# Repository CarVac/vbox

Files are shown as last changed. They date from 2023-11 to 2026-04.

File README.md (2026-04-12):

# vbox

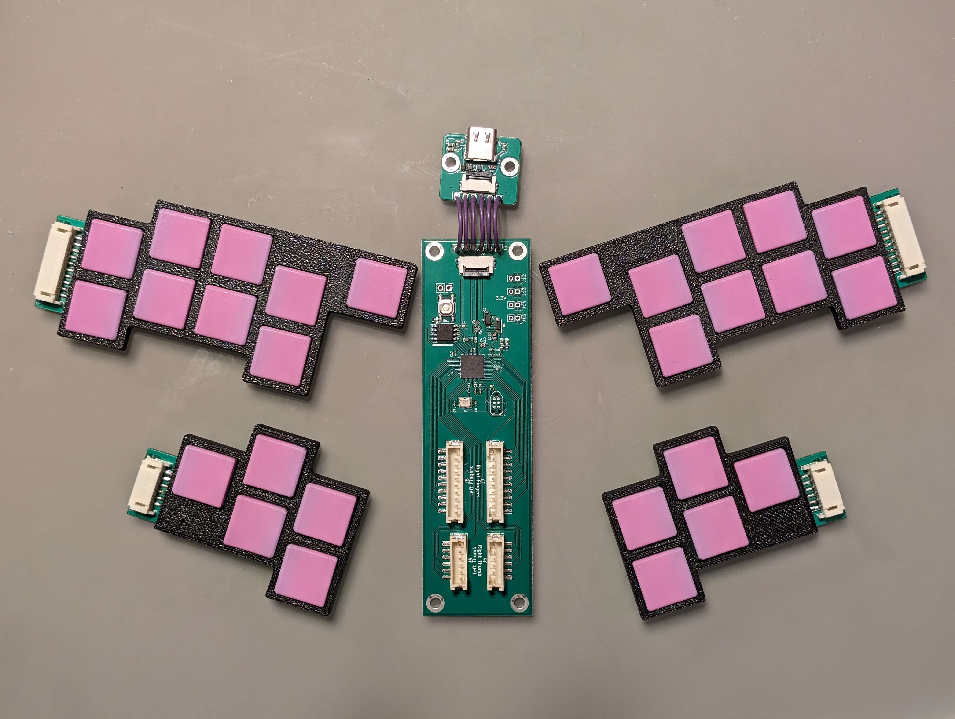
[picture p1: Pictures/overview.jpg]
Overview of pcb and hand clusters


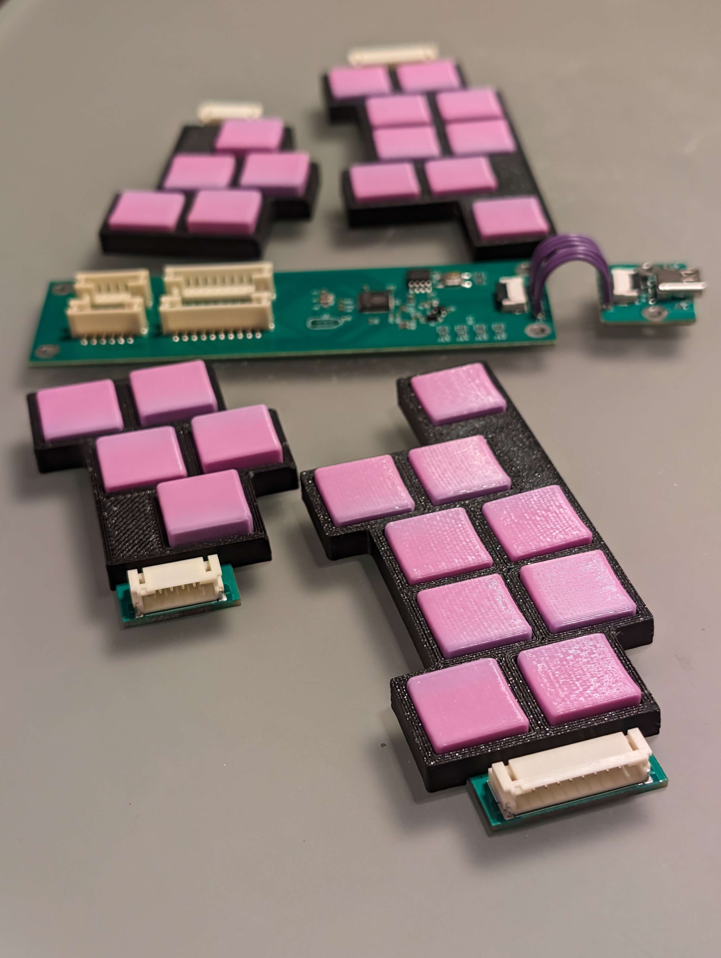
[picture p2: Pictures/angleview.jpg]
Angled view of hand clusters


A rectangle controller for Melee with buttons arranged vertically instead of on a flat surface.

It's intended to be highly modular and configurable to fit different people's button layout preferences and hand sizes.

The left- and right-hand finger clusters and thumb clusters are mirror images of each other, with shared daughterboard PCBs, each side having single-sided layouts.

The switches used are Omron D2LS-21(20M), which are easy to hand-solder. The SMD JST PH connector was chosen for its low profile and ease of hand soldering.

Any switch location can be omitted if desired, and the housing printed with a blank where it would go.

The motherboard is designed to be as narrow as possible, with 4 JST connectors for button cluster daughterboards and one FFC connector for the USB-C breakout board.

It is derived from the [Rana Labs Tadpole](https://github.com/rana-sylvatica/rana-tadpole) motherboard but with extremely heavy layout changes.

# License

This project is licensed under the CERN Open Hardware License Version 2 - Strongly Reciprocal

This license:

* Allows use, reproduction, modification, distribution, and sale of the design
* Requires distribution under the same terms and attribution to the original designer(s)
* Does not grant trademark rights
* May be terminated for non-compliance

If you are distributing vboxes or derivatives, you must provide a way for the recipient to access the source files (this repository or your fork if you modify it).

All of these files are posted as-is. This source is distributed WITHOUT ANY EXPRESS OR IMPLIED WARRANTY, INCLUDING OF MERCHANTABILITY, SATISFACTORY QUALITY, AND FITNESS FOR A PARTICULAR PURPOSE.

# BOM

## PCBs

* Motherboard (with SMT assembly)
* [QuRB](https://github.com/rana-sylvatica/QuRB)) (with SMT assembly) (USB-C breakout)
* 2x finger daughterboards (for hand assembly)
* 2x thumb daughterboards (for hand assembly)

## Electrical Parts

* 20x (or more) Omron D2LS-21(20M) mouse switches
* 2x S6B-PH-SM4-TB 6-pin right-angle surface-mount JST PH
* 2x S10B-PH-SM4-TB 10-pin right-angle surface-mount JST PH
* 2x A06KR06KR26E152A 6-pin 6" JST KR (PH-compatible) cable assembly, reversed
* 2x A10KR10KR26E102A 10-pin 4" JST KR (PH-compatible) cable assembly, reversed
* 1x 12-pin 0.5mm pitch ribbon cable, Xmm long

## Printed Parts

The housings may be customized to include or omit different button locations. Adjust the python file (which uses Build123D) where it says `EDIT THESE TO REMOVE BUTTON HOLES` and run the file to generate new STLs.

Print as many keycaps as necessary.

* Left Finger Cluster Housing
* Right Finger Cluster Housing
* Left Thumb Cluster Housing
* Right Thumb Cluster Housing
* 17x (or more) Short Keycaps
* 3x (or more) Tall Keycaps

Housing TBD; there may be a non-folding version and a folding version.

# Using the Motherboard with Other Button Clusters

You can use the motherboard with other finger clusters as long as you design them properly. The motherboard JST pinout is listed following, according to standard OpenFrame1 button locations.

## Pinout

### Left Hand Fingers

1. GND
2. Upper Row Index Finger (optional, GPIO 11)
3. Upper Row Ring Finger (optional, GPIO 23)
4. Upper Row Pinky Finger (optional, GPIO 25)
5. L
6. Analog Stick Left
7. Analog Stick Down
8. Analog Stick Right
9. Upper Row Middle Finger (optional, GPIO 1)
10. Start

### Right Hand Fingers

1. GND
2. Right Hand Start (optional, GPIO 29)
3. R
4. B
5. Y
6. X
7. Lightshield
8. Z
9. Midshield
10. Analog Stick Up

### Left Hand Thumbs

1. GND
2. Modifier 5 (optional, GPIO 10) (mirrored location of C-Stick Right)
3. Modifier 4 (optional, GPIO 9) (mirrored location of C-Stick Up)
4. Modifier 3 (optional, GPIO 8) (mirrored location of C-Stick Left)
5. ModY (mirrored location of C-Stick Down)
6. ModX (mirrored location of A)

### Right Hand Thumbs

1. GND
2. C-Stick Right
3. C-Stick Down
4. A
5. C-Stick Left
6. C-Stick Up

## Modifications

You may use as many or as few buttons as you would like, but keep in mind that if you are intending this for melee you should at least populate the standard 20 OpenFrame1 buttons.

When the JSTs of the button clusters are mounted on the **top side of the outer edges** of the PCBs (as in the reference design) or the **bottom side of the inner edges** of the PCBs, the pinout should be the same as on the motherboard, and you must use "reversed" cable assemblies which map pin 1 to pin 1 and pin N to pin N.

When the JSTs of the button clusters are mounted on the **bottom side of the outer edges** of the PCBs or the **top side of the inner edges** of the PCBs, the pinout should be reversed relative to the motherboard (1 to 10 and 10 to 1 for the fingers, and 1 to 6 and 6 to 1 for the thumb clusters) and you must use "non-reversed" (they simply omit the word reversed) cable assemblies that connect pin 1 to pin N. The correct cable assemblies are listed below:

* 2x A06KR06KR26E152**B** 6-pin 6" JST KR (PH-compatible) cable assembly, ***non-reversed***
* 2x A10KR10KR26E102**B** 10-pin 4" JST KR (PH-compatible) cable assembly, ***non-reversed***

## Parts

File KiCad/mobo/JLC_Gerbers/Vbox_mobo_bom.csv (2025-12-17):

Comment | Designator | Footprint | LCSC
1uF | C1,C2,C4,C10 | Capacitor_SMD:C_0402_1005Metric | C52923
100nF | C3,C5,C6,C11,C12,C13,C14,C15,C16,C17 | Capacitor_SMD:C_0402_1005Metric | C1525
22pF | C7,C8 | Capacitor_SMD:C_0402_1005Metric | C1555
10uF | C9 | Capacitor_SMD:C_0402_1005Metric | C15525
Schottky Diode | D1 | Diode_SMD:D_SOD-123 | C8598
Conn_01x06 | J4,J5 | Connector_JST:JST_PH_B6B-PH-SM4-TB_1x06-1MP_P2.00mm_Vertical | C471518
Conn_01x10 | J6,J7 | Connector_JST:JST_PH_B10B-PH-SM4-TB_1x10-1MP_P2.00mm_Vertical | C264997
2k | R1,R2,R3,R4,R12,R13,R14,R15,R16,R17,R18,R19,R20,R21,R22,R23,R24,R25,R26,R27,R28,R29,R30,R31,R32,R33,R34,R35 | Resistor_SMD:R_0402_1005Metric | C25552
1k | R10,R11 | Resistor_SMD:R_0402_1005Metric | C11702
5.6k | R5 | Resistor_SMD:R_0603_1608Metric | C23189
10k | R6 | Resistor_SMD:R_0603_1608Metric | C25804
10k | R7 | Resistor_SMD:R_0402_1005Metric | C25744
27 | R8,R9 | Resistor_SMD:R_0603_1608Metric | C25190
Boot | SW1 | Button_Switch_SMD:SW_SPST_SKQG_WithStem | C202424
XC6206 | U1 | Package_TO_SOT_SMD:SOT-23 | C5446
X05A26H12G | U2 | footprint:FPC-SMD_X05A26H12G | C519263
RP2040 | U3 | qw-footprints:RP2040-QFN-56 | C2040
W25Q128JVS | U4 | Package_SO:SOIC-8_5.23x5.23mm_P1.27mm | C97521
12MHz | Y1 | Crystal:Crystal_SMD_3225-4Pin_3.2x2.5mm | C9002

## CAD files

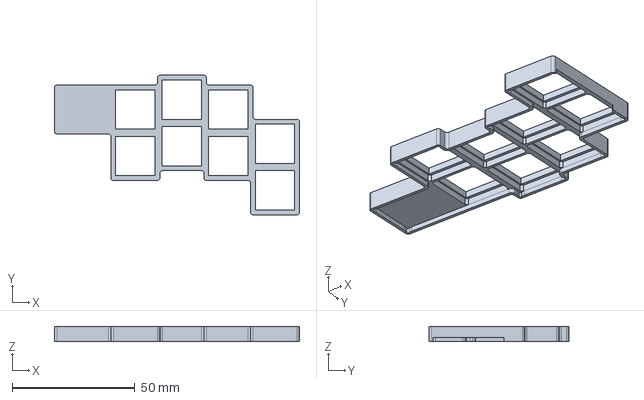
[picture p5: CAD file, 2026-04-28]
keycap/module_finger_right_8btn.step
100.0 x 57.0 x 6.00 mm

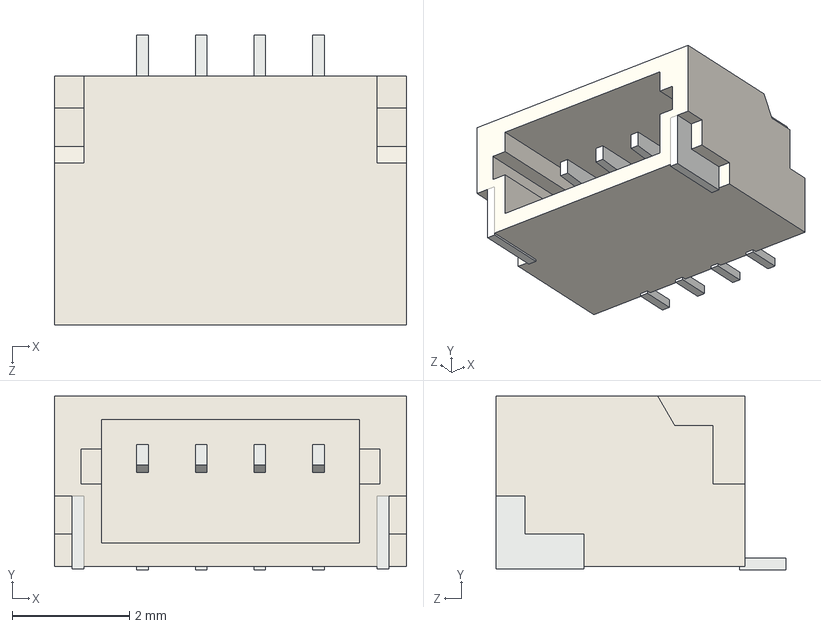
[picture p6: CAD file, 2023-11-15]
KiCad/qw-footprints/qw-footprints/JST-SM04B-SRSS-TB.STEP
6.00 x 2.96 x 4.95 mm

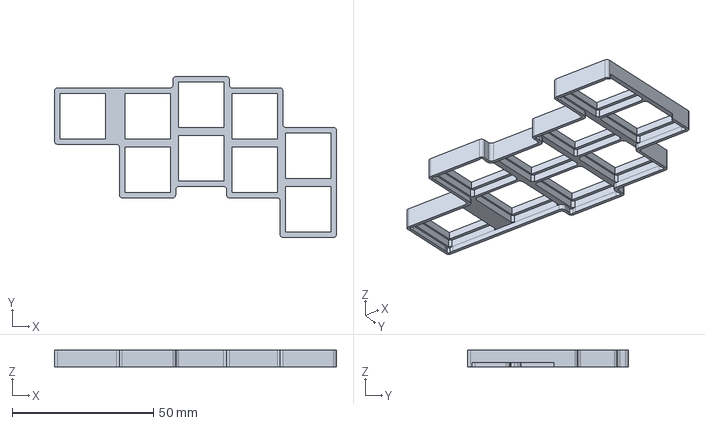
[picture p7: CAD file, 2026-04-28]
keycap/module_finger_right_9btn.step
100.0 x 57.0 x 6.00 mm

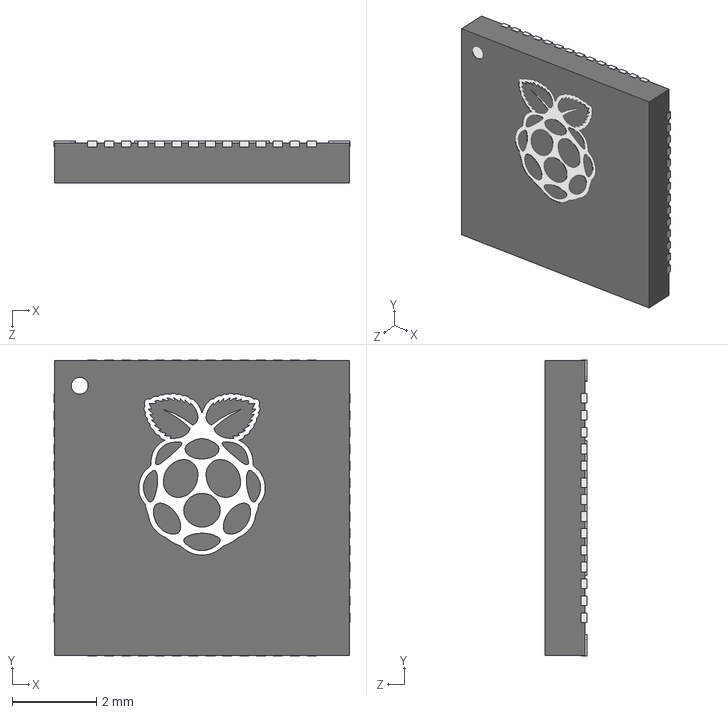
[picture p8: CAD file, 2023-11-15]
KiCad/qw-footprints/qw-footprints/RP2040_QFN_PACKAGE.STEP
7.02 x 7.02 x 1.00 mm

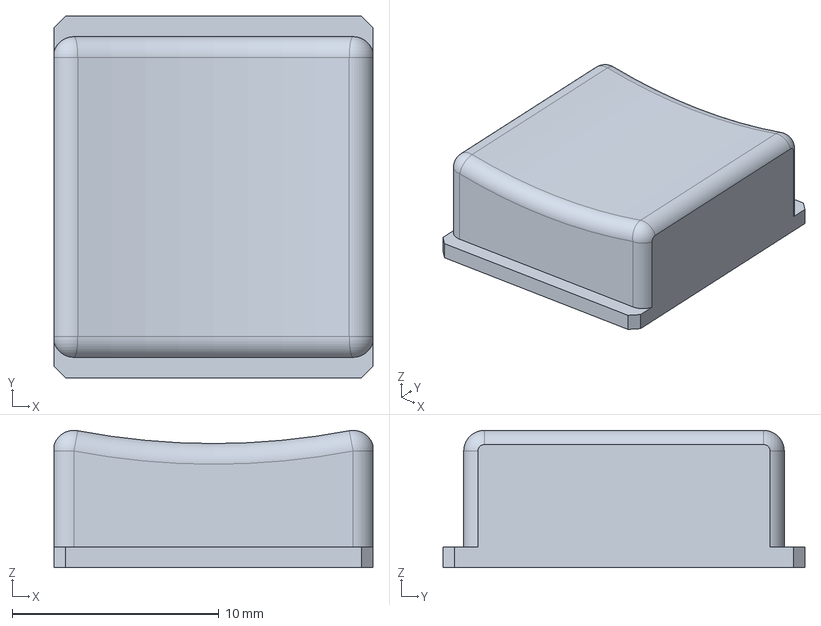
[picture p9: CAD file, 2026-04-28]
keycap/cap_tall.step
15.4 x 17.5 x 6.64 mm

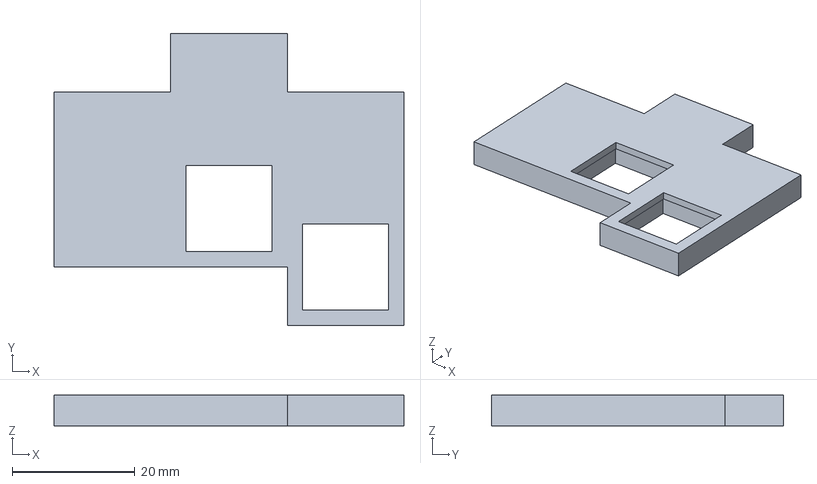
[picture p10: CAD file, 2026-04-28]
keycap/mx_thumb_left.step
57.0 x 47.5 x 5.00 mm

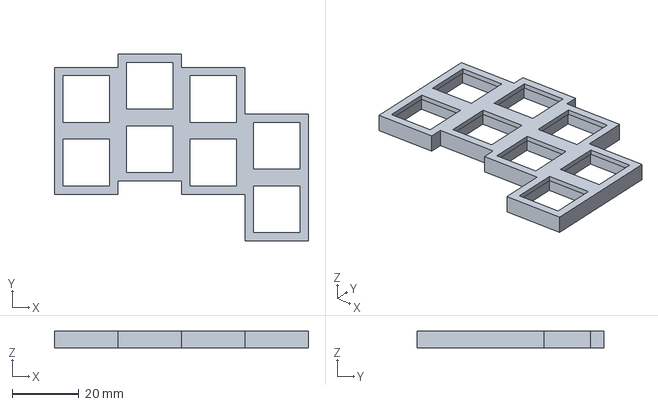
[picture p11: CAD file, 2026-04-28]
keycap/mx_finger_right.step
76.0 x 56.0 x 5.00 mm

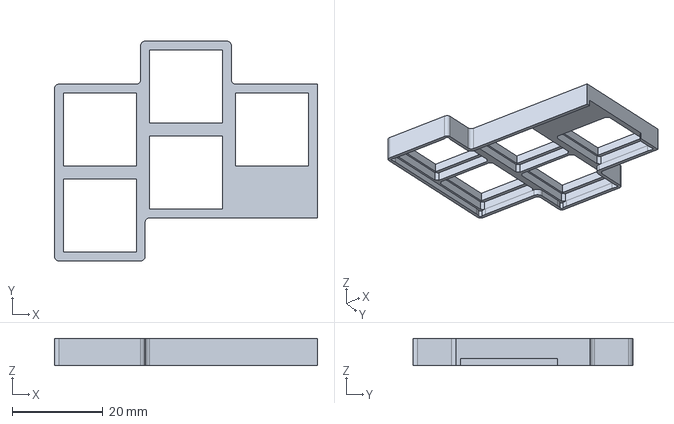
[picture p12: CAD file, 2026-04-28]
keycap/module_thumb_right.step
58.0 x 48.5 x 6.00 mm

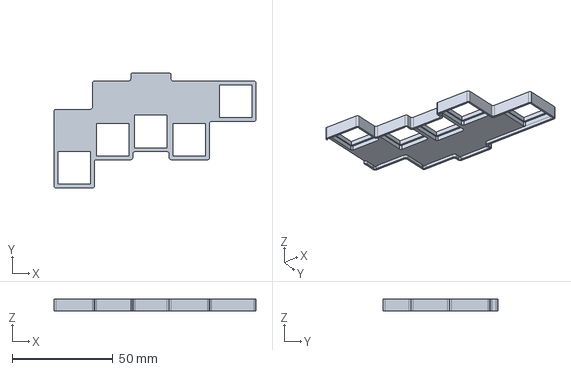
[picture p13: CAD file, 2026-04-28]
keycap/module_finger_left_5btn.step
100.0 x 57.0 x 6.00 mm

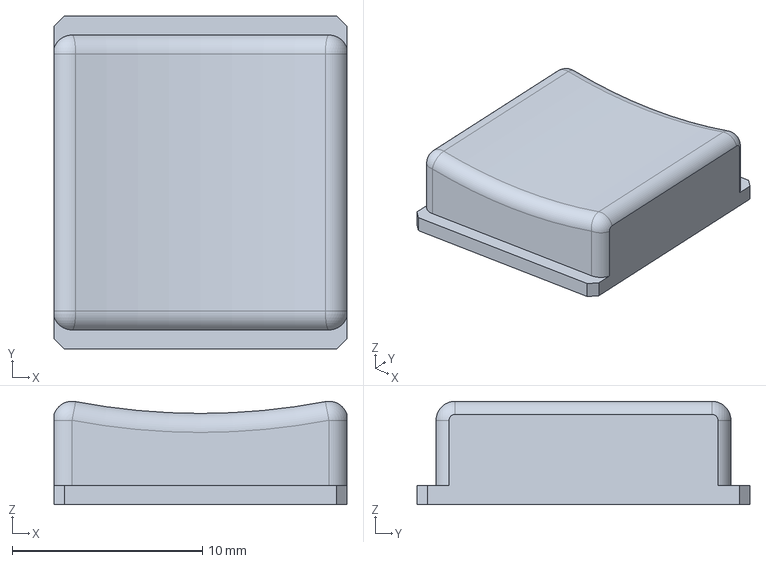
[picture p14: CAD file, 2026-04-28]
keycap/cap_short.step
15.4 x 17.5 x 5.44 mm

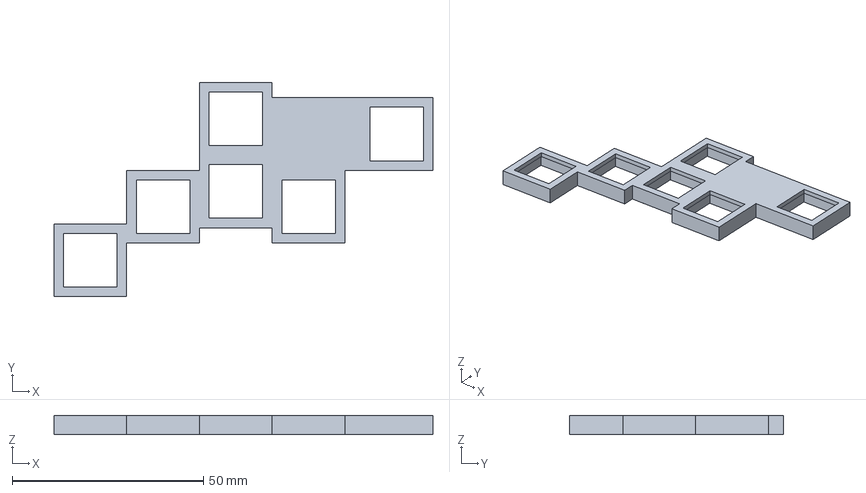
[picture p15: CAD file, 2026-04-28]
keycap/mx_finger_left_6btn.step
99.0 x 56.0 x 5.00 mm

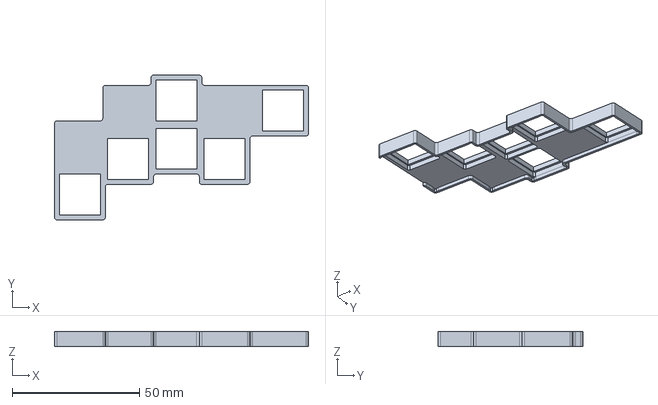
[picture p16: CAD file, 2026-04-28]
keycap/module_finger_left_6btn.step
100.0 x 57.0 x 6.00 mm

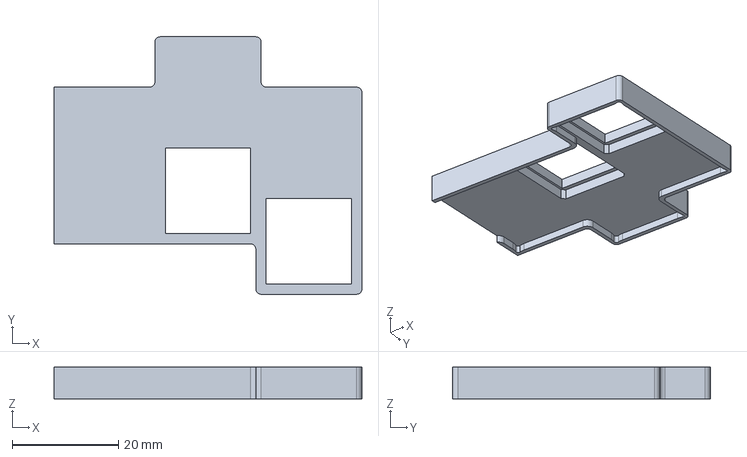
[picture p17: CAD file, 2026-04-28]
keycap/module_thumb_left_2btn.step
58.0 x 48.5 x 6.00 mm

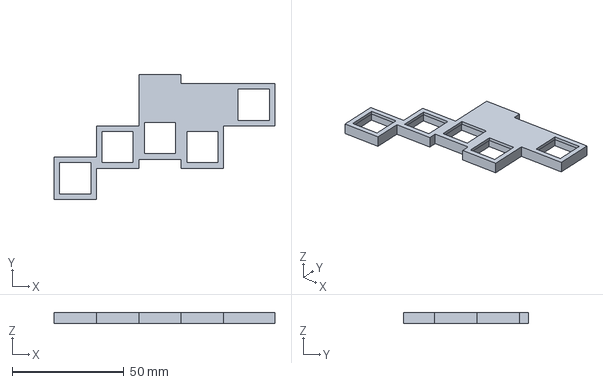
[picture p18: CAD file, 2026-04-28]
keycap/mx_finger_left_5btn.step
99.0 x 56.0 x 5.00 mm

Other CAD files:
keycap/module_finger_left_9btn.step
keycap/mx_thumb_right.step
keycap/module_thumb_left_5btn.step

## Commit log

2023-10-23 add stls for keycaps
    [short_cap.stl, tall_cap.stl]
2023-11-15 initial mobo commit, only added footprint
    [JST-SM04B-SRSS-TB.STEP, RP2040_QFN_PACKAGE.STEP, Vbox_mobo.kicad_pcb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]
2023-11-16 mobo complete...?
    [Vbox_mobo.kicad_pcb, Vbox_thumbs.kicad_pcb, Vbox_thumbs.kicad_sch]
2023-11-16 add silkscreen, increase hole size
    [Vbox_mobo.kicad_pcb]
2023-11-16 replace vias with mounting holes
    [Vbox_mobo.kicad_pcb, Vbox_mobo.kicad_sch]
2023-11-16 framework for button clusters
    [Vbox_fingers.kicad_pcb, Vbox_fingers.kicad_sch]
2023-11-16 thumbs and fingers
    [Vbox_fingers.kicad_pcb, Vbox_fingers.kicad_sch, Vbox_thumbs.kicad_pcb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]
2023-11-16 make fingers stepped
    [Vbox_fingers.kicad_pcb]
2023-11-16 add lcsc pn for mobo connectors
    [Vbox_mobo.kicad_sch]
2023-11-16 tweak outlines of button clusters
    [Vbox_fingers.kicad_pcb, Vbox_thumbs.kicad_pcb]
2023-11-16 fix drc errors
    [Vbox_fingers.kicad_pcb, Vbox_mobo.kicad_pcb, Vbox_thumbs.kicad_pcb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]
2023-11-17 adjust mounting hole position
    [Vbox_mobo.kicad_pcb]
2023-11-17 add 4 3.3v power headers
    [Vbox_mobo.kicad_pcb, Vbox_mobo.kicad_sch]
2023-11-17 realign the connectors
    [Vbox_mobo.kicad_pcb]
2023-11-17 reroute the power for the 3.3v headers
    [Vbox_mobo.kicad_pcb]
2023-11-17 add thermal clearances to fingers, a few more vias
    [Vbox_fingers.kicad_pcb, Vbox_fingers.kicad_sch, Vbox_thumbs.kicad_pcb]
2023-11-17 rotate gnd connections for mouse switches
    [Vbox_fingers.kicad_pcb, Vbox_thumbs.kicad_pcb]
2023-11-17 move traces away from hand solder pads
    [Vbox_fingers.kicad_pcb, Vbox_thumbs.kicad_pcb]
2023-11-18 add labels to connectors on mobo
    [Vbox_mobo.kicad_pcb]
2023-11-20 make both sides share holes
    [Vbox_fingers.kicad_pcb, Vbox_fingers.kicad_sch, Vbox_thumbs.kicad_pcb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]
2023-11-20 make keycap have x-shaped cutout
    [short_cap.stl, tall_cap.stl]
2023-11-20 add in more recent tweaks
    [short_cap.stl, surround.stl, tall_cap.stl]
2023-11-20 shorten chamfer
    [short_cap.stl, tall_cap.stl]
2023-11-20 flip connectors
    [Vbox_fingers.kicad_pcb, Vbox_fingers.kicad_sch, Vbox_mobo.kicad_pcb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]
2023-11-25 clarified extra mod button locations
2023-11-25 add breakout board to readme
2023-11-25 change default pads on library
    [Vbox_fingers.kicad_pcb, Vbox_thumbs.kicad_pcb]
2023-11-25 clear warnings in vbox mobo
    [Vbox_mobo.kicad_pcb]
2023-11-25 add gerbers for mobo
    [Vbox_mobo.csv, Vbox_mobo.kicad_pcb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]
2023-11-25 add button cluster gerbers
    [Vbox_fingers.kicad_pcb, Vbox_thumbs.kicad_pcb]
2023-11-25 rename bom and pos
    [Vbox_mobo_BOM.csv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]
2023-11-25 fix up unpopulated components on bom
    [Vbox_mobo.kicad_sch, Vbox_mobo_BOM.csv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]
2023-11-25 correct rotations on pos file
    [Vbox_mobo_CPL.csv]
2023-11-26 fix ugly track on mobo
    [Vbox_mobo.kicad_pcb]
2023-12-08 make mobo pads hand-solderable
    [Vbox_mobo.kicad_pcb]
2023-12-08 thumb cluster stls
    [leftthumb.stl, rightthumb.stl]
2023-12-08 add finger clusters
    [leftfinger.stl, rightfinger.stl]
2023-12-08 fix the finger housing column stagger
    [leftfinger.stl, rightfinger.stl]
2023-12-09 increase clearance for connector tab on button clusters
    [leftfinger.stl, leftthumb.stl, rightfinger.stl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]
2023-12-11 make start button lower
    [Vbox_fingers.kicad_pcb, leftfinger.stl, leftthumb.stl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]
2024-06-08 adjust finger ergo, pullup resistors on mobo
    [Vbox_fingers.kicad_pcb, Vbox_mobo.kicad_pcb, Vbox_mobo.kicad_sch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]
2025-09-26 update finger cluster 3d files
    [leftfinger.stl, leftfinger_base.stl, leftfinger_wasd.stl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]
2025-12-17 sharpen corners on surrounds
    [leftfinger_base.stl, leftfinger_wasd.stl, leftthumb_2mod.stl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]
2025-12-17 not sure what this change was
    [Vbox_mobo.kicad_sch, Vbox_mobo_bom.csv]
2026-01-10 flatten finger clusters slightly
    [Vbox_fingers.kicad_pcb]
2026-01-10 fix finger module
2026-04-12 framework one-button-module clusters
    [Vbox_fingers_framework_left.kicad_pcb, Vbox_fingers_framework_left.kicad_sch, Vbox_fingers_framework_left_blank.kicad_pcb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]
2026-04-28 add MX button modules
    [Vbox_fingers_mx_left.kicad_pcb, Vbox_fingers_mx_left.kicad_sch, Vbox_fingers_mx_right.kicad_pcb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]
2026-04-28 add mx modules, all STEPs for finger modules
    [cap_short.step, cap_tall.step, module_finger_left_5btn.step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]
